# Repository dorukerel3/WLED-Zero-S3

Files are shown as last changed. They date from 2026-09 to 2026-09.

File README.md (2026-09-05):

# WLED-Zero-S3

A complete, self-contained hardware and firmware project for a custom addressable LED lighting system: a custom-designed **ESP32-S3 controller motherboard**, three **daisy-chainable WS2812B light stick PCBs**, and a tailored build of **[WLED](https://github.com/wled/WLED) v16.0.1** configured for the exact hardware. This repository contains everything needed to reproduce the system end to end — Gerber and drill files, pick-and-place data, bills of materials, 3D STEP models, the full patched firmware source tree, and a pre-built single-file flash image.

---

## Table of Contents

- [Project Overview](#project-overview)
- [Hardware Gallery](#hardware-gallery)
- [System Architecture](#system-architecture)
- [Key Features](#key-features)
- [Motherboard](#motherboard)
- [Light Sticks](#light-sticks)
- [Firmware Customizations](#firmware-customizations)
- [Repository Contents](#repository-contents)
- [Fabrication and Assembly Files](#fabrication-and-assembly-files)
- [Flashing the Pre-Built Release](#flashing-the-pre-built-release)
- [First Boot](#first-boot)
- [Building the Firmware from Source](#building-the-firmware-from-source)
- [Author and License](#author-and-license)

---

## Project Overview

The system consists of a controller motherboard and three purpose-built LED PCBs ("light sticks") of graduated lengths. The motherboard hosts a bare **ESP32-S3-WROOM-1-N16R8** module, USB-C power and programming, Li-ion battery charging, 3.3 V regulation, a 5 V logic-level shifter for the LED data line, and a MOSFET high-side power switch that lets the firmware cut power to the LED chain entirely.

The three light sticks carry **11**, **6**, and **4** WS2812B LEDs respectively — **21 in total**, which is exactly what the firmware is compiled for (`PIXEL_COUNTS=21`). The firmware is a minimal, targeted fork of WLED `v16.0.1`: one new build environment and a one-line source patch that makes the boot power state a compile-time default, so a freshly flashed unit ships with its LED power stage off and correct switch polarity, with zero post-flash configuration.

---

## Hardware Gallery

The physical production results of the custom-designed hardware, motherboard and light sticks:

### Motherboard
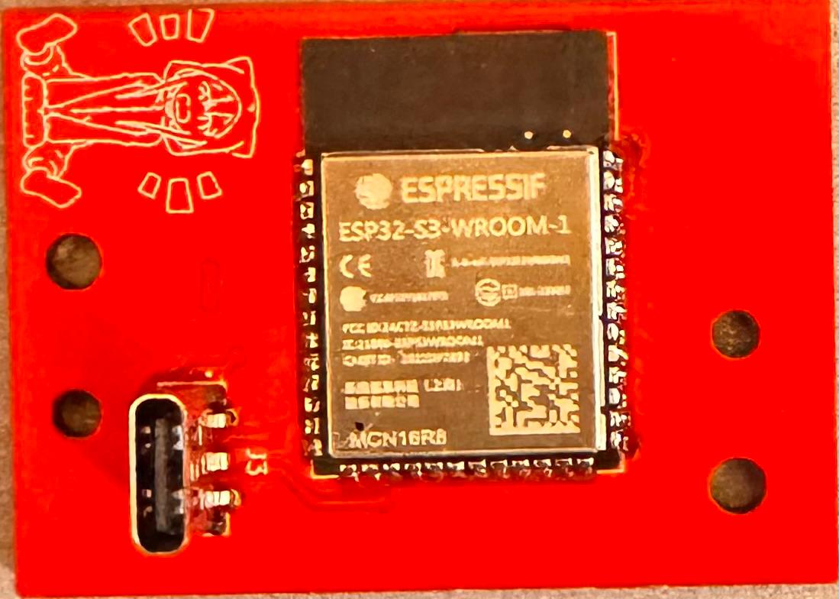
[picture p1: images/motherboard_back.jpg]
Motherboard Back
Motherboard Front 

### Longest Light Stick
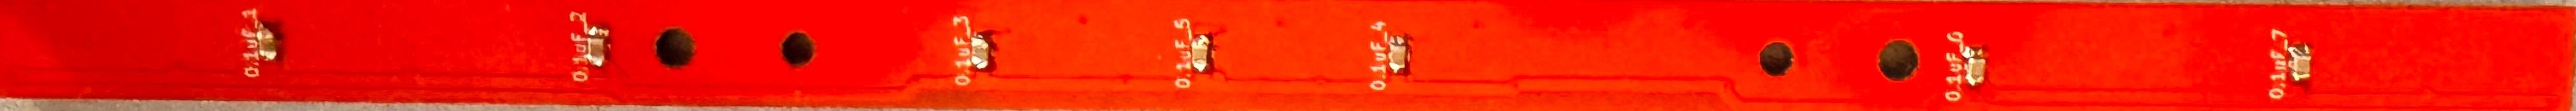
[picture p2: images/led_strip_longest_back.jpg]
Longest Light Stick Back
Longest Light Stick Front 

### Middle Light Stick
Middle Light Stick Front Middle Light Stick Back

### Shortest Light Stick
Shortest Light Stick Front Shortest Light Stick Back

---

## System Architecture

```text
 USB-C (GCT USB4220) ──► TP4057 Li-ion charger ──► Battery (B+/B− pads)
        │                                              │
        └────────────► AP2112K-3.3 LDOs ──► 3.3 V rail ──► ESP32-S3-WROOM-1-N16R8
                                                               │           │
                                            GPIO1 (LED data) ──┘           └── GPIO2 (power switch)
                                                   │                              │
                                       74AHCT1G125 level shifter        N-MOS + P-MOS high-side switch
                                                   │                              │
                                                   ▼                              ▼
                                     DIN ► Longest stick (11× WS2812B) ► Middle stick (6×) ► Shortest stick (4×)
                                                        21 LEDs total, switched 5 V rail
```

- **Data path:** the ESP32-S3 drives the WS2812B chain from `GPIO1` through a **74AHCT1G125** buffer, shifting the 3.3 V signal to clean 5 V logic for reliable data at full supply voltage.
- **Power path:** `GPIO2` controls an **N-channel + P-channel MOSFET high-side switch** (active-high) so the entire LED rail can be de-energized in software — true zero standby draw on the strip, not just black pixels.
- **Chaining:** each stick exposes `5V`, `GND`, `DIN`/`DOUT` pads, so the three boards cascade into a single 21-pixel logical strip.

---

## Key Features

- **Off-by-default boot state**, via a new `WLED_TURN_ON_AT_BOOT` compile-time flag patched into WLED's source (upstream hardcodes it to always-on).
- **Correct power-switch polarity out of the box** (`RLYPIN=2`, `RLYMDE=1`), matched to the board's active-high MOSFET high-side switch topology.
- **Single merged flashable image** — bootloader, partition table, and application combined into one `.bin` written at offset `0x0`. No multi-offset flashing.
- **16 MB flash / 8 MB octal PSRAM support**, targeting the ESP32-S3-WROOM-1-N16R8 module specifically.
- **Complete fabrication package** for all four PCBs: Gerbers, drill files, pick-and-place, BOM, and 3D STEP models.
- **Built on a stable upstream release** (`v16.0.1`), with the full source tree preserved in-repo for reproducible builds and future upstream syncs.

---

## Motherboard

| Component | Part | Package | Role |
|---|---|---|---|
| U2 | ESP32-S3-WROOM-1 (N16R8) | RF module | MCU — 16 MB flash, 8 MB octal-SPI PSRAM, WiFi/BLE |
| J3 | GCT USB4220-03-1040-C | USB-C receptacle | Power input and USB programming |
| TP4057 | TP4057 | TSOT-23-6 | Single-cell Li-ion charge management |
| AP2112_1, AP2112_2 | AP2112K-3.3 | SOT-23-5 | 3.3 V LDO regulation |
| U4 | 74AHCT1G125 | SOT-23-5 | 3.3 V → 5 V LED data level shifting |
| NMOSS1 | N-channel MOSFET | SOT-23 | Gate driver stage for the high-side switch |
| PMOSS1 | P-channel MOSFET | SOT-23 | High-side power switch for the LED rail |
| — | 8× resistors (2×1 kΩ, 2×5.1 kΩ, 3×10 kΩ, 1×330 Ω) | 0805 | Gate drive, CC1/CC2 termination, pull-ups, charge programming |
| — | 2× 1 µF capacitors | 0805 | LDO input/output decoupling |
| J2 | 1×4 pin header (DNP) | 2.54 mm | Auxiliary/debug header |
| — | 5× test points (`5V`, `B+`, `B−`, `DIN`, `GND`) | 3.0 mm pads | Bring-up and battery/strip wiring |

Full references, footprints, and datasheet links are in [`Motherboard_Files/Motherboard.csv`](Motherboard_Files/Motherboard.csv); exact placement coordinates in [`Motherboard_Files/Motherboard-all-pos.csv`](Motherboard_Files/Motherboard-all-pos.csv).

### Firmware pin map

| Signal | Pin | Configuration |
|---|-----|---|
| LED data out | GPIO1 | `DATA_PINS=1` |
| LED power switch | GPIO2 | `RLYPIN=2`, `RLYMDE=1` (active-high) |
| LED count | — | `PIXEL_COUNTS=21` |
| Flash | — | 16 MB, DIO, 40 MHz |

---

## Light Sticks

Three variants of the same design language — a 5 V WS2812B chain with per-LED 0.1 µF decoupling and pad-based chaining:

| Board | WS2812B count | Decoupling caps | Pads |
|---|---|---|---|
| Longest | 11 | 7× 0.1 µF | `5V`, `DIN`, `GND`, + |
| Middle | 6 | 3× 0.1 µF | `5V`, `DOUT`, `GND`, TP1–TP3 |
| Shortest | 4 | 2× 0.1 µF | `5V`, `DIN`, `DOUT`, `GND`, `VDD`, `VSS` |

**Total: 21 LEDs**, matching the firmware's compiled pixel count exactly. All LEDs use the `WS2812B PLCC4 5.0×5.0 mm` footprint on a 3.2 mm pitch.

---

## Firmware Customizations

Two changes on top of a clean `v16.0.1` checkout, both preserved in [`Motherboard_Files/firmware/`](Motherboard_Files/firmware/):

**[`platformio_override.ini`](Motherboard_Files/firmware/platformio_override.ini)** (new file) defines the `esp32s3` build environment:

```ini
[env:esp32s3]
extends = env:esp32s3dev_16MB_opi
build_flags = ${env:esp32s3dev_16MB_opi.build_flags}
  -D WLED_RELEASE_NAME=\"ESP32S3_Custom\"
  -D DATA_PINS=1
  -D PIXEL_COUNTS=21
  -D RLYPIN=2
  -D RLYMDE=1
  -D WLED_TURN_ON_AT_BOOT=false
```

**[`wled00/wled.h`](Motherboard_Files/firmware/wled00/wled.h)** carries a one-line patch exposing `turnOnAtBoot` as a build flag, since upstream WLED hardcodes it:

```diff
// LED CONFIG
-WLED_GLOBAL bool turnOnAtBoot _INIT(true);                 // turn on LEDs at power-up
+#ifndef WLED_TURN_ON_AT_BOOT
+  #define WLED_TURN_ON_AT_BOOT true
+#endif
+WLED_GLOBAL bool turnOnAtBoot _INIT(WLED_TURN_ON_AT_BOOT); // turn on LEDs at power-up
```

This build sets the flag to `false`, so the LED power stage never energizes without explicit user action.

---

## Repository Contents

```text
.
├── Motherboard_Files/
│   ├── firmware/                                        Full WLED v16.0.1 source tree (patched: wled00/wled.h,
│   │                                                    new: platformio_override.ini)
│   ├── WLED_16.0.1_ESP32-S3_16MB_opi_MERGED_dio40m_v2.bin   Pre-built merged flash image (write at 0x0)
│   ├── Motherboard_Gerber&Drill.zip                     Fabrication files (Cu, mask, paste, silkscreen, edge cuts, PTH/NPTH drill)
│   ├── Motherboard.csv                                  Bill of materials
│   ├── Motherboard-all-pos.csv                          Pick-and-place component positions
│   └── Motherboard_Design.step                          3D model
├── Longest_Light_Stick_Files/                           11× WS2812B — pads: 5V, DIN, GND
│   ├── Longest_light_stick_Gerber&Drill.zip             Fabrication files (Cu, mask, paste, silkscreen, edge cuts, PTH/NPTH drill)
│   ├── Longest_light_stick.csv                          Bill of materials (11× WS2812B, 7× 0.1 µF 0805)
│   ├── Longest_light_stick-all-pos.csv                  Pick-and-place component positions
│   └── Longest_Light_Stick_Design.step                  3D model
├── Middle_Light_Stick_Files/                            6× WS2812B — pads: 5V, DOUT, GND, TP1–TP3
│   ├── Middle_light_stick_Gerber&Drill.zip              Fabrication files (Cu, mask, paste, silkscreen, edge cuts, PTH/NPTH drill)
│   ├── Middle_light_stick.csv                           Bill of materials (6× WS2812B, 3× 0.1 µF 0805)
│   ├── Middle_light_stick-all-pos.csv                   Pick-and-place component positions
│   └── Middle_Light_Stick_Design.STEP                   3D model
├── Shortest_Light_Stick_Files/                          4× WS2812B — pads: 5V, DIN, DOUT, GND, VDD, VSS
│   ├── Shortest_light_stick_Gerber&Drill.zip            Fabrication files (Cu, mask, paste, silkscreen, edge cuts, PTH/NPTH drill)
│   ├── Shortest_light_stick.csv                         Bill of materials (4× WS2812B, 2× 0.1 µF 0805)
│   ├── Shortest_light_stick-all-pos.csv                 Pick-and-place component positions
│   └── Shortest_Light_Stick_Design.STEP                 3D model
├── images/                                              README gallery assets
│   ├── motherboard_front.jpg                            Assembled motherboard, component side
│   ├── motherboard_back.jpg                             Assembled motherboard, reverse side
│   ├── led_strip_longest_front.jpg                      Longest light stick, LED side
│   ├── led_strip_longest_back.jpg                       Longest light stick, reverse side
│   ├── led_strip_middle_front.jpg                       Middle light stick, LED side
│   ├── led_strip_middle_back.jpg                        Middle light stick, reverse side
│   ├── led_strip_shortest_front.jpg                     Shortest light stick, LED side
│   └── led_strip_shortest_back.jpg                      Shortest light stick, reverse side
├── LICENSE                                              MIT license
└── README.md                                            This document
```

---

## Fabrication and Assembly Files

Each of the four PCB folders is a complete manufacturing package:

- **`*_Gerber&Drill.zip`** — full Gerber set (front/back copper, solder mask, paste, silkscreen, board outline) plus PTH and NPTH Excellon drill files, ready to upload to any fab (JLCPCB, PCBWay, etc.).
- **`*.csv`** — the bill of materials with references, quantities, footprints, and datasheet links.
- **`*-all-pos.csv`** — pick-and-place position files (X/Y, rotation, side) for assembly services.
- **`*.step`** — 3D STEP models for enclosure design and mechanical verification.

---

## Flashing the Pre-Built Release

1. Download [`Motherboard_Files/WLED_16.0.1_ESP32-S3_16MB_opi_MERGED_dio40m_v2.bin`](Motherboard_Files/WLED_16.0.1_ESP32-S3_16MB_opi_MERGED_dio40m_v2.bin).
2. Install [esptool](https://github.com/espressif/esptool):
   ```bash
   python -m pip install esptool
   ```
3. Put the board into download mode if it doesn't reset into it automatically: hold **BOOT**, tap **RESET**, release **BOOT**.
4. Erase and flash (replace `COMx` with the board's serial port):
   ```bash
   python -m esptool --chip esp32s3 --port COMx erase_flash
   python -m esptool --chip esp32s3 --port COMx --baud 921600 write_flash 0x0 WLED_16.0.1_ESP32-S3_16MB_opi_MERGED_dio40m_v2.bin
   ```
   The image is a single merge of bootloader, partition table, and application, so it is written at offset `0x0` with no further offsets needed.

---

## First Boot

1. The board opens a WiFi access point named `WLED-AP`, password `wled1234`.
2. Connect to it and browse to `4.3.2.1` to enter your home WiFi credentials.
3. Once joined, reach the UI at `http://wled-XXXXXX.local` (`XXXXXX` is the last 6 hex digits of the board's MAC address — visible in the esptool output during flashing, or via your router's DHCP client list if `.local` doesn't resolve).
4. LEDs and the power switch stay off on every boot by default — no configuration required. Turn them on from the UI when ready.

---

<p align="center">
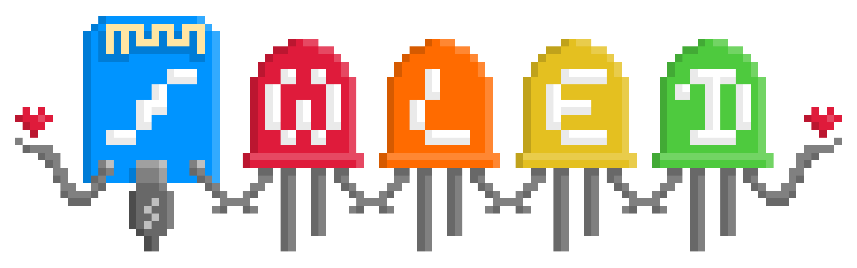
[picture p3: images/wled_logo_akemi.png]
WLED Akemi logo
  
</p>

## Building the Firmware from Source

```bash
git clone https://github.com/dorukerel3/WLED-Zero-S3.git
cd WLED-Zero-S3/Motherboard_Files/firmware
python -m pip install platformio
python -m platformio run -e esp32s3
```

This produces `.pio/build/esp32s3/firmware.bin` (application only). To reproduce the merged single-file release image:

```bash
python -m esptool --chip esp32s3 merge_bin \
  -o WLED_16.0.1_ESP32-S3_16MB_opi_MERGED_dio40m_v2.bin \
  --flash_mode dio --flash_freq 40m --flash_size 16MB \
  0x0     .pio/build/esp32s3/bootloader.bin \
  0x8000  .pio/build/esp32s3/partitions.bin \
  0x10000 .pio/build/esp32s3/firmware.bin
```

---

## Author and License

Designed and developed by **Doruk Erel** — [dorukerel.com](https://dorukerel.com).

Firmware based on [WLED](https://github.com/wled/WLED). Released under the **MIT License**. See the [`LICENSE`](LICENSE) file for the full text.

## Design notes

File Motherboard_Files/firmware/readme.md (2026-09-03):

# Custom WLED Board (ESP32-S3)

A custom firmware build of [WLED](https://github.com/wled/WLED) v16.0.1, targeting a bare **ESP32-S3-WROOM-1-N16R8** module driving an addressable LED strip through a GPIO-switched MOSFET power stage. Developed as the firmware layer for a custom-designed LED controller board, the build is configured so that a freshly flashed unit ships with LEDs off and correct power-switch polarity by default, with no post-flash configuration required. PCB fabrication and assembly (motherboard and light stick designs) are documented separately via their own Gerber deliverables and are outside the scope of this repository.

---

## Table of Contents

- [Project Overview](#project-overview)
- [Hardware Gallery](#hardware-gallery)
- [Key Features](#key-features)
- [Hardware Specifications](#hardware-specifications)
- [Firmware Customizations](#firmware-customizations)
- [Repository Contents](#repository-contents)
- [Flashing a Pre-Built Release](#flashing-a-pre-built-release)
- [First Boot](#first-boot)
- [Building from Source](#building-from-source)
- [Author and License](#author-and-license)

---

## Project Overview

This repository is a `v16.0.1` fork of WLED with a minimal, targeted set of changes on top: a PlatformIO build environment for the ESP32-S3-WROOM-1-N16R8 module, and a one-line source patch that makes the "turn on at boot" behavior a compile-time default instead of a runtime setting a user has to configure. Everything else is unmodified upstream WLED, retained via full git history so the fork can track future upstream releases.

The goal is an appliance-grade default: a unit flashed straight from a release binary boots with its LED power stage off and correctly oriented for the board's MOSFET switching circuit, without requiring anyone to open the web UI and change settings first.

---

## Hardware Gallery

The physical production results of the custom-designed hardware, motherboard and light sticks:

### Motherboard
Motherboard Front Motherboard Back

### Longest Light Stick
Longest Light Stick Front Longest Light Stick Back

### Middle Light Stick
Middle Light Stick Front Middle Light Stick Back

### Shortest Light Stick
Shortest Light Stick Front Shortest Light Stick Back

---

## Key Features

- **Off-by-default boot state**, via a new `WLED_TURN_ON_AT_BOOT` compile-time flag patched into WLED's source (upstream hardcodes this to always-on).
- **Correct power-switch polarity out of the box**, matching the board's N-channel + P-channel MOSFET high-side switch topology.
- **Single merged flashable image**, combining bootloader, partition table, and application into one `.bin` written at offset `0x0` — no multi-offset flashing required.
- **16MB flash / 8MB octal PSRAM support**, targeting the ESP32-S3-WROOM-1-N16R8 module specifically.
- **Built on a stable upstream release** (`v16.0.1`), with the fork's full commit history preserved for future upstream syncs.

---

## Hardware Specifications

| Component | Specification |
|---|---|
| Microcontroller | `ESP32-S3-WROOM-1-N16R8` — 16 MB flash, 8 MB octal-SPI PSRAM |
| LED data pin | GPIO1 |
| LED count | 21 |
| Power switch pin | GPIO2, active-low, driving an N-channel + P-channel MOSFET high-side switch |
| Flash configuration | 16 MB, DIO mode, 40 MHz |

---

## Firmware Customizations

Two changes on top of a clean `v16.0.1` checkout, both committed in this repository's history:

**`platformio_override.ini`** (new file) defines the `esp32s3` build environment — pin assignments, LED count, relay/MOSFET pin and polarity, and release naming.

**`wled00/wled.h`** carries a one-line patch exposing `turnOnAtBoot` as a build flag, since upstream WLED hardcodes it:

```diff
// LED CONFIG
-WLED_GLOBAL bool turnOnAtBoot _INIT(true);                // turn on LEDs at power-up
+#ifndef WLED_TURN_ON_AT_BOOT
+  #define WLED_TURN_ON_AT_BOOT true
+#endif
+WLED_GLOBAL bool turnOnAtBoot _INIT(WLED_TURN_ON_AT_BOOT); // turn on LEDs at power-up
```

This build sets the flag to `false`, so the power stage never energizes without explicit user action.

---

## Repository Contents

```text
.
├── wled00/                 WLED firmware source (patched: wled.h)
├── boards/                 Board pin-mapping definitions
├── lib/                    Bundled third-party libraries
├── tools/                  Build tooling and custom partition tables
├── platformio.ini          Upstream WLED build environments
├── platformio_override.ini Custom esp32s3 build environment (this fork's config)
├── LICENSE                 Upstream MIT license
└── readme.md
```

The repository is otherwise a standard WLED checkout — see the [upstream project](https://github.com/wled/WLED) for full documentation on the underlying firmware.

---

## Flashing a Pre-Built Release

1. Download the latest merged `.bin` from the [Releases](../../releases) page.
2. Install [esptool](https://github.com/espressif/esptool):
   ```bash
   python -m pip install esptool
   ```
3. Put the board into download mode if it doesn't reset into it automatically: hold **BOOT**, tap **RESET**, release **BOOT**.
4. Erase and flash (replace `COMx` with the board's serial port):
   ```bash
   python -m esptool --chip esp32s3 --port COMx erase_flash
   python -m esptool --chip esp32s3 --port COMx --baud 921600 write_flash 0x0 WLED_ESP32-S3_16MB_opi_MERGED.bin
   ```
   The image is a single merge of bootloader, partition table, and application, so it's written at offset `0x0` with no further offsets needed.

---

## First Boot

1. The board opens a WiFi access point named `WLED-AP`, password `wled1234`.
2. Connect to it and browse to `4.3.2.1` to enter your home WiFi credentials.
3. Once joined, reach the UI at `http://wled-XXXXXX.local` (`XXXXXX` is the last 6 hex digits of the board's MAC address — visible in the esptool output during flashing, or via your router's DHCP client list if `.local` doesn't resolve).
4. LEDs and the power switch stay off on every boot by default — no configuration required. Turn them on from the UI when ready.

---

## Building from Source

```bash
git clone <this-repo-url>
cd <this-repo>
python -m pip install platformio
python -m platformio run -e esp32s3
```

This produces `.pio/build/esp32s3/firmware.bin` (application only). To reproduce the merged, single-file release image:

```bash
python -m esptool --chip esp32s3 merge_bin \
  -o WLED_ESP32-S3_16MB_opi_MERGED.bin \
  --flash_mode dio --flash_freq 40m --flash_size 16MB \
  0x0     .pio/build/esp32s3/bootloader.bin \
  0x8000  .pio/build/esp32s3/partitions.bin \
  0x10000 .pio/build/esp32s3/firmware.bin
```

---

## Author and License

Developed by **Doruk Erel**.

Based on [WLED](https://github.com/wled/WLED). Released under the **MIT License**. See the `LICENSE` file for the full text.

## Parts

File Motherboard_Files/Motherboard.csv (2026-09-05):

Id | Designator | Footprint | Quantity | Designation | Supplier and ref
1 | 1KOHM_1, 1KOHM_2, 5.1kohm_1, 5.1kohm_2, 10Kohm_1, 10Kohm_2, 10Kohm_3, 330ohm_1 | R_0805_2012Metric_Pad1.20x1.40mm_HandSolder | 8 | R
2 | 1uF_1, 1uF_2 | C_0805_2012Metric_Pad1.18x1.45mm_HandSolder | 2 | C
3 | 5V1, B+1, B-1, DIN1, GND1 | TestPoint_Pad_3.0x3.0mm | 5 | TestPoint_Square
4 | 74AHCT1G125 | SOT-23-5_HandSoldering | 1 | 74AHCT1G125
5 | AP2112_1, AP2112_2 | SOT-23-5 | 2 | AP2112K-3.3
6 | D_Schottky_1, D_Schottky_2 | D_SMA_Handsoldering | 2 | D_Schottky
7 | J3 | GCT_USB4220-03-1040-C_REVA | 1 | USB4220-03-1040-C_REVA
8 | NMOSS1 | SOT-23 | 1 | Q_NMOS_GSD
9 | PMOSS1 | SOT-23 | 1 | Q_PMOS_GSD
10 | TP4057 | TSOT-23-6 | 1 | TP4057
11 | U2 | ESP32-S3-WROOM-1 | 1 | ESP32-S3-WROOM-1

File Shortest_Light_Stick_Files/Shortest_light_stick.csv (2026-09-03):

Id | Designator | Footprint | Quantity | Designation | Supplier and ref
1 | 0.1uF_1, 0.1uF_2 | C_0805_2012Metric_Pad1.18x1.45mm_HandSolder | 2 | C
2 | 5V, DIN, DOUT, GND, VDD, VSS | TestPoint_Pad_3.0x3.0mm | 6 | TestPoint_Square
3 | D1, D2, D3, D4 | LED_WS2812B_PLCC4_5.0x5.0mm_P3.2mm | 4 | WS2812B

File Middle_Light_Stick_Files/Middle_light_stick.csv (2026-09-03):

Id | Designator | Footprint | Quantity | Designation | Supplier and ref
1 | 0.1uF_1, 0.1uF_2, 0.1uF_3 | C_0805_2012Metric_Pad1.18x1.45mm_HandSolder | 3 | C
2 | 5V, DOUT, GND, TP1, TP2, TP3 | TestPoint_Pad_3.0x3.0mm | 6 | TestPoint_Square
3 | D1, D2, D3, D4, D5, D6 | LED_WS2812B_PLCC4_5.0x5.0mm_P3.2mm | 6 | WS2812B

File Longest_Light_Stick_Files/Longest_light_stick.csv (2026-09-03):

Id | Designator | Footprint | Quantity | Designation | Supplier and ref
1 | 0.1uF_1, 0.1uF_2, 0.1uF_3, 0.1uF_4, 0.1uF_5, 0.1uF_6, 0.1uF_7 | C_0805_2012Metric_Pad1.18x1.45mm_HandSolder | 7 | C
2 | 5V | TestPoint_Pad_3.0x3.0mm | 1 | 5V
3 | D1, D2, D3, D4, D5, D6, D10, D11, D12, D13, D14 | LED_WS2812B_PLCC4_5.0x5.0mm_P3.2mm | 11 | WS2812B
4 | DIN | TestPoint_Pad_3.0x3.0mm | 1 | DIN
5 | DOUT | TestPoint_Pad_3.0x3.0mm | 1 | DOUT
6 | GND | TestPoint_Pad_3.0x3.0mm | 1 | GND
7 | VDD | TestPoint_Pad_3.0x3.0mm | 1 | VDD
8 | VSS | TestPoint_Pad_3.0x3.0mm | 1 | VSS

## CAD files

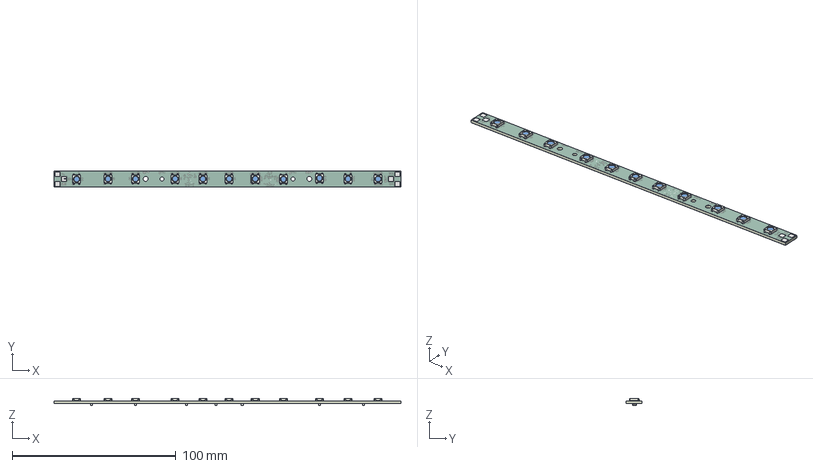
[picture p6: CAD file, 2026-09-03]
Longest_Light_Stick_Files/Longest_Light_Stick_Design.step
212.0 x 10.0 x 4.53 mm
LED_WS2812B_PLCC4_5.0x5.0mm_P3.2mm x 11
C_0805_2012Metric x 7
Longest_light_stick_copper
Longest_light_stick_pad
Longest_light_stick_via
Longest_light_stick_silkscreen x 2
Longest_light_stick_soldermask x 2
Longest_light_stick_PCB

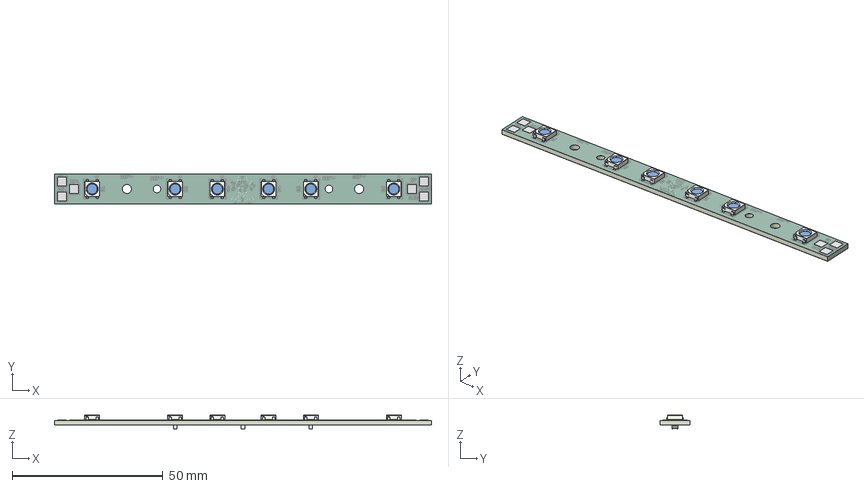
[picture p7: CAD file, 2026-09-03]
Middle_Light_Stick_Files/Middle_Light_Stick_Design.STEP
125.0 x 10.0 x 4.53 mm
LED_WS2812B_PLCC4_5.0x5.0mm_P3.2mm x 6
C_0805_2012Metric x 3
Middle_light_stick_copper
Middle_light_stick_pad
Middle_light_stick_via
Middle_light_stick_silkscreen x 2
Middle_light_stick_soldermask x 2
Middle_light_stick_PCB

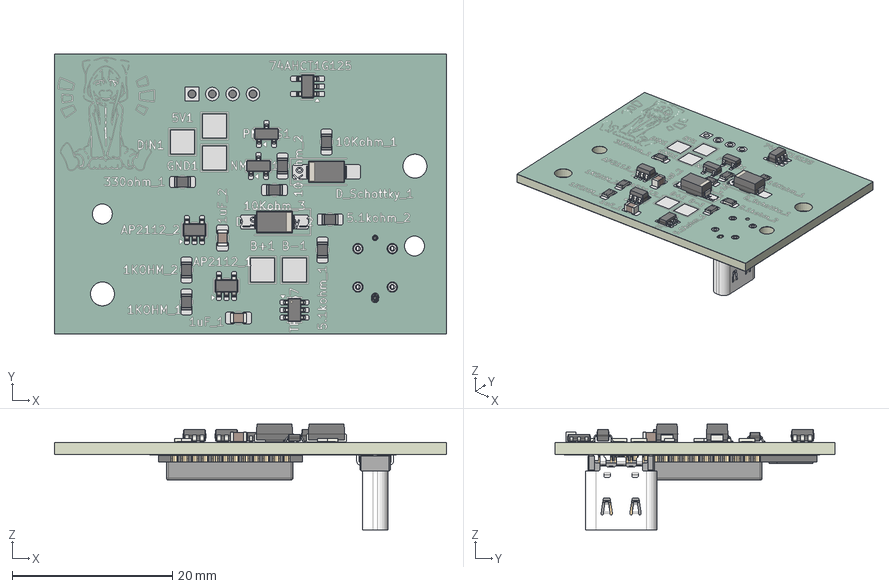
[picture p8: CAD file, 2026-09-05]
Motherboard_Files/Motherboard_Design.STEP
49.0 x 35.0 x 13.2 mm
D_SMA x 2
R_0805_2012Metric x 8
SOT-23-5 x 3
SOT-23 x 2
C_0805_2012Metric x 2
TSOT-23-6
USB4220-03-0930-C_PART1
USB4220-03-0930-C_PART2
ESP32-S3-WROOM-1
Motherboard_copper
Motherboard_pad
Motherboard_via
Motherboard_silkscreen x 2
Motherboard_soldermask x 2
Motherboard_PCB

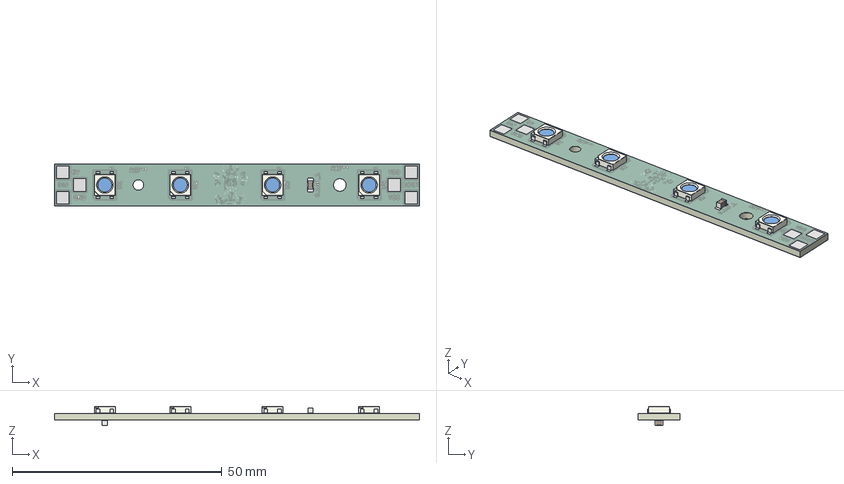
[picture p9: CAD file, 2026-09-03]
Shortest_Light_Stick_Files/Shortest_Light_Stick_Design.STEP
87.0 x 10.0 x 4.53 mm
LED_WS2812B_PLCC4_5.0x5.0mm_P3.2mm x 4
C_0805_2012Metric x 2
Shortest_light_stick_copper
Shortest_light_stick_pad
Shortest_light_stick_via
Shortest_light_stick_silkscreen x 2
Shortest_light_stick_soldermask x 2
Shortest_light_stick_PCB

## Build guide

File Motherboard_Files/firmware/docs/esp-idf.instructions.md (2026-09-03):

---
applyTo: "**/*.cpp,**/*.h,**/*.hpp,**/*.ino"
---
# ESP-IDF Coding Guide (within arduino-esp32)

WLED runs on the Arduino-ESP32 framework, which wraps ESP-IDF. Understanding the ESP-IDF layer is essential when writing chip-specific code, managing peripherals, or preparing for the IDF v5.x migration. This guide documents patterns already used in the codebase and best practices derived from Espressif's official examples.

> **Scope**: This file is an optional review guideline. It applies when touching chip-specific code, peripheral drivers, memory allocation, or platform conditionals.

> **Note for AI review tools**: sections enclosed in
> `<!-- HUMAN_ONLY_START -->` / `<!-- HUMAN_ONLY_END -->` HTML comments contain
> contributor reference material. Do **not** use that content as actionable review
> criteria — treat it as background context only.

---

<!-- HUMAN_ONLY_START -->
## Identifying the Build Target: `CONFIG_IDF_TARGET_*`

Use `CONFIG_IDF_TARGET_*` macros to gate chip-specific code at compile time. These are set by the build system and are mutually exclusive — exactly one is defined per build.

| Macro | Chip | Architecture | Notes |
|---|---|---|---|
| `CONFIG_IDF_TARGET_ESP32` | ESP32 (classic) | Xtensa dual-core | Primary target. Has DAC, APLL, I2S ADC mode |
| `CONFIG_IDF_TARGET_ESP32S2` | ESP32-S2 | Xtensa single-core | Limited peripherals. 13-bit ADC |
| `CONFIG_IDF_TARGET_ESP32S3` | ESP32-S3 | Xtensa dual-core | Preferred for large installs. Octal PSRAM, USB-OTG |
| `CONFIG_IDF_TARGET_ESP32C3` | ESP32-C3 | RISC-V single-core | Minimal peripherals. RISC-V clamps out-of-range float→unsigned casts |
| `CONFIG_IDF_TARGET_ESP32C5` | ESP32-C5 | RISC-V single-core | Wi-Fi 2.4Ghz + 5Ghz, Thread/Zigbee. Future target |
| `CONFIG_IDF_TARGET_ESP32C6` | ESP32-C6 | RISC-V single-core | Wi-Fi 6, Thread/Zigbee. Future target |
| `CONFIG_IDF_TARGET_ESP32P4` | ESP32-P4 | RISC-V dual-core | High performance. Future target |

<!-- HUMAN_ONLY_END -->
### Build-time validation
WLED validates at compile time that exactly one target is defined and that it is a supported chip (`wled.cpp` lines 39–61). Follow this pattern when adding new chip-specific branches:

<!-- HUMAN_ONLY_START -->
```cpp
#if defined(CONFIG_IDF_TARGET_ESP32)
  // classic ESP32 path
#elif defined(CONFIG_IDF_TARGET_ESP32S3)
  // S3-specific path
#elif defined(CONFIG_IDF_TARGET_ESP32C3) || defined(CONFIG_IDF_TARGET_ESP32C5) || defined(CONFIG_IDF_TARGET_ESP32C6) || defined(CONFIG_IDF_TARGET_ESP32P4)
  // RISC-V common path
#else
  #warning "Untested chip — review peripheral availability"
#endif
```

<!-- HUMAN_ONLY_END -->
### Guidelines

- **Always test on the actual chip** before claiming support. Simulators and cross-compilation can hide peripheral differences.
- **Prefer `#elif` chains** over nested `#ifdef` for readability.
- **Do not use `CONFIG_IDF_TARGET_*` for feature detection.** Use `SOC_*` capability macros instead (see next section). For example, use `SOC_I2S_SUPPORTS_ADC` instead of `CONFIG_IDF_TARGET_ESP32` to check for I2S ADC support.
- When a feature must be disabled on certain chips, use explicit `static_assert()` or `#warning` directives so the build clearly reports what is missing.

---

## Hardware Capability Detection: `SOC_*` Macros

`SOC_*` macros (from `soc/soc_caps.h`) describe what the current chip supports. They are the correct way to check for peripheral features — they stay accurate when new chips are added, unlike `CONFIG_IDF_TARGET_*` checks.

<!-- HUMAN_ONLY_START -->
### Important `SOC_*` macros used in WLED

| Macro | Type | Used in | Purpose |
|---|---|---|---|
| `SOC_I2S_NUM` | `int` | `audio_source.h` | Number of I2S peripherals (1 or 2) |
| `SOC_I2S_SUPPORTS_ADC` | `bool` | `usermods/audioreactive/audio_source.h` | I2S ADC sampling mode (ESP32 only) |
| `SOC_I2S_SUPPORTS_APLL` | `bool` | `usermods/audioreactive/audio_source.h` | Audio PLL for precise sample rates |
| `SOC_I2S_SUPPORTS_PDM_RX` | `bool` | `usermods/audioreactive/audio_source.h` | PDM microphone input |
| `SOC_ADC_MAX_BITWIDTH` | `int` | `util.cpp` | ADC resolution (12 or 13 bits). Renamed to `CONFIG_SOC_ADC_RTC_MAX_BITWIDTH` in IDF v5 |
| `SOC_ADC_CHANNEL_NUM(unit)` | `int` | `pin_manager.cpp` | ADC channels per unit |
| `SOC_UART_NUM` | `int` | `dmx_input.cpp` | Number of UART peripherals |
| `SOC_DRAM_LOW` / `SOC_DRAM_HIGH` | `addr` | `util.cpp` | DRAM address boundaries for validation |

<!-- HUMAN_ONLY_END -->
### Key pitfall
`SOC_ADC_MAX_BITWIDTH` (ADC resolution 12 or 13 bits) was renamed to `CONFIG_SOC_ADC_RTC_MAX_BITWIDTH` in IDF v5.

<!-- HUMAN_ONLY_START -->
### Less commonly used but valuable

| Macro | Purpose |
|---|---|
| `SOC_RMT_TX_CANDIDATES_PER_GROUP` | Number of RMT TX channels (varies 2–8 by chip) |
| `SOC_LEDC_CHANNEL_NUM` | Number of LEDC (PWM) channels |
| `SOC_GPIO_PIN_COUNT` | Total GPIO pin count |
| `SOC_DAC_SUPPORTED` | Whether the chip has a DAC (ESP32/S2 only) |
| `SOC_SPIRAM_SUPPORTED` | Whether PSRAM interface exists |
| `SOC_CPU_CORES_NUM` | Core count (1 or 2) — useful for task pinning decisions |

<!-- HUMAN_ONLY_END -->

### Best practices

```cpp
// Good: feature-based detection
#if SOC_I2S_SUPPORTS_PDM_RX
  _config.mode = i2s_mode_t(I2S_MODE_MASTER | I2S_MODE_RX | I2S_MODE_PDM);
#else
  #warning "PDM microphones not supported on this chip"
#endif

// Avoid: chip-name-based detection
#if defined(CONFIG_IDF_TARGET_ESP32) || defined(CONFIG_IDF_TARGET_ESP32S3)
  // happens to be correct today, but breaks when a new chip adds PDM support
#endif
```

<!-- HUMAN_ONLY_START -->
### PSRAM capability macros

For PSRAM presence, mode, and DMA access patterns:

| Macro | Meaning |
|---|---|
| `CONFIG_SPIRAM` / `BOARD_HAS_PSRAM` | PSRAM is present in the build configuration |
| `CONFIG_SPIRAM_MODE_QUAD` | Quad-SPI PSRAM (standard, used on ESP32 classic and some S2/S3 boards) |
| `CONFIG_SPIRAM_MODE_OCT` | Octal-SPI PSRAM — 8 data lines, DTR mode. Used on ESP32-S3 with octal PSRAM (e.g. N8R8 / N16R8 modules). Reserves GPIO 33–37 for the PSRAM bus — **do not allocate these pins** when this macro is defined. `wled.cpp` uses this to gate GPIO reservation. |
| `CONFIG_SPIRAM_MODE_HEX` | Hex-SPI (16-line) PSRAM — future interface on ESP32-P4 running at up to 200 MHz. Used in `json.cpp` to report the PSRAM mode. |
| `CONFIG_SOC_PSRAM_DMA_CAPABLE` | PSRAM buffers can be used with DMA (ESP32-S3 with octal PSRAM) |
| `CONFIG_SOC_MEMSPI_FLASH_PSRAM_INDEPENDENT` | SPI flash and PSRAM on separate buses (no speed contention) |

<!-- HUMAN_ONLY_END -->

#### Detecting octal/hex flash

On ESP32-S3 modules with OPI flash (e.g. N8R8 modules where the SPI flash itself runs in Octal-PI mode), the build system sets:

| Macro | Meaning |
|---|---|
| `CONFIG_ESPTOOLPY_FLASHMODE_OPI` | Octal-PI flash mode. On S3, implies GPIO 33–37 are used by the flash/PSRAM interface — the same GPIO block as octal PSRAM. `wled.cpp` uses `CONFIG_ESPTOOLPY_FLASHMODE_OPI \|\| (CONFIG_SPIRAM_MODE_OCT && BOARD_HAS_PSRAM)` to decide whether to reserve these GPIOs. `json.cpp` uses this to report the flash mode string as `"🚀OPI"`. |
| `CONFIG_ESPTOOLPY_FLASHMODE_HEX` | Hex flash mode (ESP32-P4). Reported as `"🚀🚀HEX"` in `json.cpp`. |

**Pattern used in WLED** (from `wled.cpp`) to reserve the octal-bus GPIOs on S3:
```cpp
#if defined(CONFIG_IDF_TARGET_ESP32S3)
  #if CONFIG_ESPTOOLPY_FLASHMODE_OPI || (CONFIG_SPIRAM_MODE_OCT && defined(BOARD_HAS_PSRAM))
    // S3: GPIO 33-37 are used by the octal PSRAM/flash bus
    managed_pin_type pins[] = { {33, true}, {34, true}, {35, true}, {36, true}, {37, true} };
    pinManager.allocateMultiplePins(pins, sizeof(pins)/sizeof(managed_pin_type), PinOwner::SPI_RAM);
  #endif
#endif
```

---

## ESP-IDF Version Conditionals

<!-- HUMAN_ONLY_START -->
### Checking the IDF version

```cpp
#include <esp_idf_version.h>

#if ESP_IDF_VERSION >= ESP_IDF_VERSION_VAL(5, 0, 0)
  // IDF v5+ code path
#elif ESP_IDF_VERSION >= ESP_IDF_VERSION_VAL(4, 4, 0)
  // IDF v4.4+ code path
#else
  // Legacy IDF v3/v4.x path
#endif
```

### Key ESP-IDF version thresholds for WLED

| Version | What changed |
|---|---|
| **4.0.0** | Filesystem API (`SPIFFS`/`LittleFS`), GPIO driver overhaul |
| **4.2.0** | ADC/GPIO API updates; `esp_adc_cal` introduced |
| **4.4.0** | I2S driver refactored (legacy API remains); `adc_deprecated.h` headers appear for newer targets |
| **4.4.4–4.4.8** | Known I2S channel-swap regression on ESP32 (workaround in `audio_source.h`) |
| **5.0.0** | **Major breaking changes** — RMT, I2S, ADC, SPI flash APIs replaced (see migration section) |
| **5.1.0** | Matter protocol support; new `esp_flash` API stable |
| **5.3+** | arduino-esp32 v3.x compatibility; C6/P4 support |

<!-- HUMAN_ONLY_END -->
### Guidelines

- When adding a version guard, **always include a comment** explaining *what* changed and *why* the guard is needed.
- Avoid version ranges that silently break — prefer `>=` over exact version matches.
- Known regressions should use explicit range guards:
  ```cpp
  // IDF 4.4.4–4.4.8 swapped I2S left/right channels (fixed in 4.4.9)
  #if (ESP_IDF_VERSION >= ESP_IDF_VERSION_VAL(4, 4, 4)) && \
      (ESP_IDF_VERSION <= ESP_IDF_VERSION_VAL(4, 4, 8))
    #define I2S_CHANNELS_SWAPPED
  #endif
  ```

---

## Migrating from ESP-IDF v4.4.x to v5.x

The jump from IDF v4.4 (arduino-esp32 v2.x) to IDF v5.x (arduino-esp32 v3.x) is the largest API break in ESP-IDF history. This section documents the critical changes and recommended migration patterns based on the upstream WLED `V5` branch (`https://github.com/wled/WLED/tree/V5`). Note: WLED has not yet migrated to IDF v5 — these patterns prepare for the future migration.

<!-- HUMAN_ONLY_START -->
### Compiler changes

IDF v5.x ships a much newer GCC toolchain. Key versions:

| ESP-IDF | GCC | C++ default | Notes |
|---|---|---|---|
| 4.4.x (current) | **8.4.0** | C++17 (gnu++17) | Xtensa + RISC-V |
| 5.1–5.3 | **13.2** | C++20 (gnu++2b) | Significant warning changes |
| 5.4–5.5 | **14.2** | C++23 (gnu++2b) | Latest; stricter diagnostics |

Notable behavioral differences:

| Change | Impact | Action |
|---|---|---|
| Stricter `-Werror=enum-conversion` | Implicit int-to-enum casts now error | Use explicit `static_cast<>` or typed enums |
| C++20/23 features available | `consteval`, `concepts`, `std::span`, `std::expected` | Use judiciously — ESP8266 builds still require GCC 10.x with C++17 |
| `-Wdeprecated-declarations` enforced | Deprecated API calls become warnings/errors | Migrate to new APIs (see below) |
| `-Wdangling-reference` (GCC 13+) | Warns when a reference binds to a temporary that will be destroyed | Fix the lifetime issue; do not suppress the warning |
| `-fno-common` default (GCC 12+) | Duplicate tentative definitions across translation units cause linker errors | Use `extern` declarations in headers, define in exactly one `.cpp` |
| RISC-V codegen improvements | C3/C6/P4 benefit from better register allocation | No action needed — automatic |

### C++ language features: GCC 8 → GCC 14

The jump from GCC 8.4 to GCC 14.2 spans six major compiler releases. This section lists features that become available and patterns that need updating.

#### Features safe to use after migration

These work in GCC 13+/14+ but **not** in GCC 8.4. Guard with `#if ESP_IDF_VERSION >= ESP_IDF_VERSION_VAL(5, 0, 0)` if the code must compile on both IDF v4 and v5.

| Feature | Standard | Example | Benefit |
|---|---|---|---|
| Designated initializers (C++20) | C++20 | `gpio_config_t cfg = { .mode = GPIO_MODE_OUTPUT };` | Already used as a GNU extension in GCC 8; becomes standard and portable in C++20 |
| `[[likely]]` / `[[unlikely]]` | C++20 | `if (err != ESP_OK) [[unlikely]] { ... }` | Hints for branch prediction; useful in hot paths |
| `[[nodiscard("reason")]]` | C++20 | `[[nodiscard("leak if ignored")]] void* allocBuffer();` | Enforces checking return values — helpful for `esp_err_t` wrappers |
| `std::span<T>` | C++20 | `void process(std::span<uint8_t> buf)` | Safe, non-owning view of contiguous memory — replaces raw pointer + length pairs |
| `consteval` | C++20 | `consteval uint32_t packColor(...)` | Guarantees compile-time evaluation; useful for color constants |
| `constinit` | C++20 | `constinit static int counter = 0;` | Prevents static initialization order fiasco |
| Concepts / `requires` | C++20 | `template<typename T> requires std::integral<T>` | Clearer constraints than SFINAE; improves error messages |
| Three-way comparison (`<=>`) | C++20 | `auto operator<=>(const Version&) const = default;` | Less boilerplate for comparable types |
| `std::bit_cast` | C++20 | `float f = std::bit_cast<float>(uint32_val);` | Type-safe reinterpretation — replaces `memcpy` or `union` tricks |
| `if consteval` | C++23 | `if consteval { /* compile-time */ } else { /* runtime */ }` | Cleaner than `std::is_constant_evaluated()` |
| `std::expected<T, E>` | C++23 | `std::expected<int, esp_err_t> readSensor()` | Monadic error handling — cleaner than returning error codes |
| `std::to_underlying` | C++23 | `auto val = std::to_underlying(myEnum);` | Replaces `static_cast<int>(myEnum)` |

#### Features already available in GCC 8 (C++17)

These work on both IDF v4.4 and v5.x — prefer them now:

| Feature | Example | Notes |
|---|---|---|
| `if constexpr` | `if constexpr (sizeof(T) == 4) { ... }` | Compile-time branching; already used in WLED |
| `std::optional<T>` | `std::optional<uint8_t> pin;` | Nullable value without sentinel values like `-1` |
| `std::string_view` | `void log(std::string_view msg)` | Non-owning, non-allocating string reference |
| Structured bindings | `auto [err, value] = readSensor();` | Useful with `std::pair` / `std::tuple` returns |
| Fold expressions | `(addSegment(args), ...);` | Variadic template expansion |
| Inline variables | `inline constexpr int MAX_PINS = 50;` | Avoids ODR issues with header-defined constants |
| `[[maybe_unused]]` | `[[maybe_unused]] int debug_only = 0;` | Suppresses unused-variable warnings cleanly |
| `[[fallthrough]]` | `case 1: doA(); [[fallthrough]]; case 2:` | Documents intentional switch fallthrough |
| Nested namespaces | `namespace wled::audio { }` | Shorter than nested `namespace` blocks |

#### Patterns that break or change behavior

| Pattern | GCC 8 behavior | GCC 14 behavior | Fix |
|---|---|---|---|
| `int x; enum E e = x;` | Warning (often ignored) | Error with `-Werror=enum-conversion` | `E e = static_cast<E>(x);` |
| `int g;` in two `.cpp` files | Both compile, linker merges (tentative definition) | Error: multiple definitions (`-fno-common`) | `extern int g;` in header, `int g;` in one `.cpp` |
| `const char* ref = std::string(...).c_str();` | Silent dangling pointer | Warning (`-Wdangling-reference`) | Extend lifetime: store the `std::string` in a local variable |
| `register int x;` | Accepted (ignored) | Warning or error (`register` removed in C++17) | Remove `register` keyword |
| Narrowing in aggregate init | Warning | Error | Use explicit cast or wider type |
| Implicit `this` capture in lambdas | Accepted in `[=]` | Deprecated warning; error in C++20 mode | Use `[=, this]` or `[&]` |

<!-- HUMAN_ONLY_END -->
#### Recommendations

- **Do not raise the minimum C++ standard yet.** WLED must still build on IDF v4.4 (GCC 8.4, C++17). Use `#if __cplusplus > 201703L` to gate C++20 features.
- **Mark intentional fallthrough** with `[[fallthrough]]` — GCC 14 warns on unmarked fallthrough by default.
<!-- HUMAN_ONLY_START -->
- **Prefer `std::optional` over sentinel values** (e.g., `-1` for "no pin") in new code — it works on both compilers.
- **Use `std::string_view`** for read-only string parameters instead of `const char*` or `const String&` — zero-copy and works on GCC 8+.
- **Avoid raw `union` type punning** — prefer `memcpy` (GCC 8) or `std::bit_cast` (GCC 13+) for strict-aliasing safety.

<!-- HUMAN_ONLY_END -->
### Deprecated and removed APIs

#### RMT (Remote Control Transceiver)

The legacy `rmt_*` functions are removed in IDF v5. Do not introduce new legacy RMT calls.

<!-- HUMAN_ONLY_START -->
The new API is channel-based:

| IDF v4 (legacy) | IDF v5 (new) | Notes |
|---|---|---|
| `rmt_config()` + `rmt_driver_install()` | `rmt_new_tx_channel()` / `rmt_new_rx_channel()` | Channels are now objects |
| `rmt_write_items()` | `rmt_transmit()` with encoder | Requires `rmt_encoder_t` |
| `rmt_set_idle_level()` | Configure in channel config | Set at creation time |
| `rmt_item32_t` | `rmt_symbol_word_t` | Different struct layout |

<!-- HUMAN_ONLY_END -->
**WLED impact**: NeoPixelBus LED output and IR receiver both use legacy RMT. The upstream `V5` branch adds `-D WLED_USE_SHARED_RMT` and disables IR until the library is ported.

#### I2S (Inter-IC Sound)

Legacy `i2s_driver_install()` + `i2s_read()` API is deprecated. When touching audio source code, wrap legacy I2S init and reading in `#if ESP_IDF_VERSION_MAJOR < 5` / `#else`.

<!-- HUMAN_ONLY_START -->
 The new API uses channel handles:
| IDF v4 (legacy) | IDF v5 (new) | Notes |
|---|---|---|
| `i2s_driver_install()` | `i2s_channel_init_std_mode()` | Separate STD/PDM/TDM modes |
| `i2s_set_pin()` | Pin config in `i2s_std_gpio_config_t` | Set at init time |
| `i2s_read()` | `i2s_channel_read()` | Uses channel handle |
| `i2s_set_clk()` | `i2s_channel_reconfig_std_clk()` | Reconfigure running channel |
| `i2s_config_t` | `i2s_std_config_t` | Separate config for each mode |

**Migration pattern** (from Espressif examples):
```cpp
#if ESP_IDF_VERSION >= ESP_IDF_VERSION_VAL(5, 0, 0)
  #include "driver/i2s_std.h"
  i2s_chan_handle_t rx_handle;
  i2s_chan_config_t chan_cfg = I2S_CHANNEL_DEFAULT_CONFIG(I2S_NUM_0, I2S_ROLE_MASTER);
  i2s_new_channel(&chan_cfg, NULL, &rx_handle);

  i2s_std_config_t std_cfg = {
    .clk_cfg  = I2S_STD_CLK_DEFAULT_CONFIG(22050),
    .slot_cfg = I2S_STD_MSB_SLOT_DEFAULT_CONFIG(I2S_DATA_BIT_WIDTH_32BIT, I2S_SLOT_MODE_MONO),
    .gpio_cfg = { .din = GPIO_NUM_32, .mclk = I2S_GPIO_UNUSED, ... },
  };
  i2s_channel_init_std_mode(rx_handle, &std_cfg);
  i2s_channel_enable(rx_handle);
#else
  // Legacy i2s_driver_install() path
#endif
```
<!-- HUMAN_ONLY_END -->
**WLED impact**: The audioreactive usermod (`audio_source.h`) heavily uses legacy I2S. Migration requires rewriting the `I2SSource` class for channel-based API.

<!-- HUMAN_ONLY_START -->
#### ADC (Analog-to-Digital Converter)

Legacy `adc1_get_raw()` and `esp_adc_cal_*` are deprecated:

| IDF v4 (legacy) | IDF v5 (new) | Notes |
|---|---|---|
| `adc1_config_width()` + `adc1_get_raw()` | `adc_oneshot_new_unit()` + `adc_oneshot_read()` | Object-based API |
| `esp_adc_cal_characterize()` | `adc_cali_create_scheme_*()` | Calibration is now scheme-based |
| `adc_continuous_*` (old) | `adc_continuous_*` (restructured) | Config struct changes |

#### SPI Flash

| IDF v4 (legacy) | IDF v5 (new) |
|---|---|
| `spi_flash_read()` | `esp_flash_read()` |
| `spi_flash_write()` | `esp_flash_write()` |
| `spi_flash_erase_range()` | `esp_flash_erase_region()` |

WLED already has a compatibility shim in `ota_update.cpp` that maps old names to new ones.

#### GPIO

| IDF v4 (legacy) | IDF v5 (recommended) |
|---|---|
| `gpio_pad_select_gpio()` | `esp_rom_gpio_pad_select_gpio()` (or use `gpio_config()`) |
| `gpio_set_direction()` + `gpio_set_pull_mode()` | `gpio_config()` with `gpio_config_t` struct |

### Features disabled in IDF v5 builds

The upstream `V5` branch explicitly disables features with incompatible library dependencies:

```ini
# platformio.ini [esp32_idf_V5]
-D WLED_DISABLE_INFRARED       # IR library uses legacy RMT
-D WLED_DISABLE_MQTT            # AsyncMqttClient incompatible with IDF v5
-D ESP32_ARDUINO_NO_RGB_BUILTIN # Prevents RMT driver conflict with built-in LED
-D WLED_USE_SHARED_RMT          # Use new shared RMT driver for NeoPixel output
```

<!-- HUMAN_ONLY_END -->
### Migration checklist for new code

1. **Never use a removed API without a version guard.** Always provide both old and new paths, or disable the feature on IDF v5.
2. **Test on both IDF v4.4 and v5.x builds** if the code must be backward-compatible.
3. **Prefer the newer API** when writing new code — wrap the old API in an `#else` block.
4. **Mark migration TODOs** with `// TODO(idf5):` so they are easy to find later.

---

## Memory Management: `heap_caps_*` Best Practices

ESP32 has multiple memory regions with different capabilities. Using the right allocator is critical for performance and stability.

<!-- HUMAN_ONLY_START -->
### Memory regions

| Region | Flag | Speed | DMA | Size | Use for |
|---|---|---|---|---|---|
| DRAM | `MALLOC_CAP_INTERNAL \| MALLOC_CAP_8BIT` | Fast | Yes (ESP32) | 200–320 KB | Hot-path buffers, task stacks, small allocations |
| IRAM | `MALLOC_CAP_EXEC` | Fastest | No | 32–128 KB | Code (automatic via `IRAM_ATTR`) |
| PSRAM (SPIRAM) | `MALLOC_CAP_SPIRAM \| MALLOC_CAP_8BIT` | Slower | Chip-dependent | 2–16 MB | Large buffers, JSON documents, image data |
| RTC RAM | `MALLOC_CAP_RTCRAM` | Moderate | No | 8 KB | Data surviving deep sleep; small persistent buffers |

<!-- HUMAN_ONLY_END -->

### WLED allocation wrappers

WLED provides convenience wrappers with automatic fallback. **Always prefer these over raw `heap_caps_*` calls**:

| Function | Allocation preference | Use case |
|---|---|---|
| `d_malloc(size)` | RTC → DRAM → PSRAM | General-purpose; prefers fast memory |
| `d_calloc(n, size)` | Same as `d_malloc`, zero-initialized | Arrays, structs |
| `p_malloc(size)` | PSRAM → DRAM | Large buffers; prefers abundant memory |
| `p_calloc(n, size)` | Same as `p_malloc`, zero-initialized | Large arrays |
| `d_malloc_only(size)` | RTC → DRAM (no PSRAM fallback) | DMA buffers, time-critical data |

### PSRAM guidelines

- **Check availability**: test availability with `psramFound() && ESP.getPsramSize() > 0` before assuming PSRAM is present. Never rely on `BOARD_HAS_PSRAM`only.
- **DMA compatibility**: on ESP32 (classic), PSRAM buffers are **not DMA-capable** — use `d_malloc_only()` to allocate DMA buffers in DRAM only. On ESP32-S3 with octal PSRAM (`CONFIG_SPIRAM_MODE_OCT`), PSRAM buffers *can* be used with DMA when `CONFIG_SOC_PSRAM_DMA_CAPABLE` is defined.
- **JSON documents**: use the `PSRAMDynamicJsonDocument` allocator (defined in `wled.h`) to put large JSON documents in PSRAM:
  ```cpp
  PSRAMDynamicJsonDocument doc(16384);  // allocated in PSRAM if available
  ```
- **Fragmentation**: PSRAM allocations fragment less than DRAM because the region is larger. But avoid mixing small and large allocations in PSRAM — small allocations waste the MMU page granularity.
- **Heap validation**: use `d_measureHeap()` and `d_measureContiguousFreeHeap()` to monitor remaining DRAM. Allocations that would drop free DRAM below `MIN_HEAP_SIZE` should go to PSRAM instead.
- **Performance**: Keep hot-path data in DRAM. Prefer PSRAM for capacity-oriented buffers and monitor contiguous DRAM headroom.
<!-- HUMAN_ONLY_START -->
   PSRAM access is up to 15× slower than DRAM on ESP32, 3–10× slower than DRAM on ESP32-S3/-S2 with quad-SPI bus. On ESP32-S3 with octal PSRAM (`CONFIG_SPIRAM_MODE_OCT`), the penalty is smaller (~2×) because the 8-line DTR bus can transfer 8 bits in parallel at 80 MHz (120 MHz is possible with CONFIG_SPIRAM_SPEED_120M, which requires enabling experimental ESP-IDF features). On ESP32-P4 with hex PSRAM (`CONFIG_SPIRAM_MODE_HEX`), the 16-line bus runs at 200 MHz which brings it on-par with DRAM. Keep hot-path data in DRAM regardless, but consider that ESP32 often crashes when the largest DRAM chunk gets below 10 KB.
<!-- HUMAN_ONLY_END -->

<!-- HUMAN_ONLY_START -->
### Pattern: preference-based allocation

When you need a buffer that works on boards with or without PSRAM:

```cpp
// Prefer PSRAM for large buffers, fall back to DRAM
uint8_t* buf = (uint8_t*)heap_caps_malloc_prefer(bufSize, 2,
    MALLOC_CAP_SPIRAM | MALLOC_CAP_8BIT,   // first choice: PSRAM
    MALLOC_CAP_DEFAULT);                    // fallback: any available
// Or simply:
uint8_t* buf = (uint8_t*)p_malloc(bufSize);
```

<!-- HUMAN_ONLY_END -->
---

## I2S Audio: Best Practices

The audioreactive usermod uses I2S for microphone input. Key patterns:

### Port selection

```cpp
constexpr i2s_port_t AR_I2S_PORT = I2S_NUM_0;
// I2S_NUM_1 has limitations: no MCLK routing, no ADC support, no PDM support
```

Always use `I2S_NUM_0` unless you have a specific reason and have verified support on all target chips.

### DMA buffer tuning

DMA buffer size controls latency vs. reliability:

| Scenario | `dma_buf_count` | `dma_buf_len` | Latency | Notes |
|---|---|---|---|---|
| With HUB75 matrix | 18 | 128 | ~100 ms | Higher count prevents I2S starvation during matrix DMA |
| Without PSRAM | 24 | 128 | ~140 ms | More buffers compensate for slower interrupt response |
| Default | 8 | 128 | ~46 ms | Acceptable for most setups |

### Interrupt priority

Choose interrupt priority based on coexistence with other drivers:

```cpp
#ifdef WLED_ENABLE_HUB75MATRIX
  .intr_alloc_flags = ESP_INTR_FLAG_IRAM | ESP_INTR_FLAG_LEVEL1,  // level 1 (lowest) to avoid starving HUB75
#else
  .intr_alloc_flags = ESP_INTR_FLAG_LEVEL2 | ESP_INTR_FLAG_LEVEL3,  // accept level 2 or 3 (allocator picks available)
#endif
```

### APLL (Audio PLL) usage

The ESP32 has an audio PLL for precise sample rates. Rules:

- Enable APLL when an MCLK pin is provided and precision matters.
- **Disable APLL** when Ethernet or HUB75 is active — they also use the APLL.
- APLL is broken on ESP32 revision 0 silicon.
- Not all chips have APLL — gate with `SOC_I2S_SUPPORTS_APLL`.

```cpp
#if !defined(SOC_I2S_SUPPORTS_APLL)
  _config.use_apll = false;
#elif defined(WLED_USE_ETHERNET) || defined(WLED_ENABLE_HUB75MATRIX)
  _config.use_apll = false;  // APLL conflict
#endif
```

### PDM microphone caveats

- Not supported on ESP32-C3 (`SOC_I2S_SUPPORTS_PDM_RX` not defined).
- ESP32-S3 PDM has known issues: sample rate at 50% of expected, very low amplitude.
  - **16-bit data width**: Espressif's IDF documentation states that in PDM mode the data unit width is always 16 bits, regardless of the configured `bits_per_sample`.
  - See [espressif/esp-idf#8660](https://github.com/espressif/esp-idf/issues/8660) for the upstream issue.
  - **Flag `bits_per_sample = I2S_BITS_PER_SAMPLE_32BIT` in PDM mode** — this causes the S3 low-amplitude symptom.
- No clock pin (`I2S_CKPIN = -1`) triggers PDM mode in WLED.

---

## HUB75 LED Matrix: Best Practices

WLED uses the `ESP32-HUB75-MatrixPanel-I2S-DMA` library for HUB75 matrix output.

### Chip-specific panel limits

```cpp
#if defined(CONFIG_IDF_TARGET_ESP32S3) && defined(BOARD_HAS_PSRAM)
  maxChainLength = 6;   // S3 + PSRAM: up to 6 panels (DMA-capable PSRAM)
#elif defined(CONFIG_IDF_TARGET_ESP32S2)
  maxChainLength = 2;   // S2: limited DMA channels
#else
  maxChainLength = 4;   // Classic ESP32: default
#endif
```

### Color depth vs. pixel count

The driver dynamically reduces color depth for larger displays to stay within DMA buffer limits:

| Pixel count | Color depth | Bits per pixel |
|---|---|---|
| ≤ `MAX_PIXELS_10BIT` | 10-bit (30-bit color) | High quality (experimental) |
| ≤ `MAX_PIXELS_8BIT` | 8-bit (24-bit color) | Full quality |
| ≤ `MAX_PIXELS_6BIT` | 6-bit (18-bit color) | Slight banding |
| ≤ `MAX_PIXELS_4BIT` | 4-bit (12-bit color) | Visible banding |
| larger | 3-bit (9-bit color) | Minimal color range |

### Resource conflicts

- **APLL**: HUB75 I2S DMA uses the APLL. Disable APLL in the audio I2S driver when HUB75 is active.
- **I2S peripheral**: HUB75 uses `I2S_NUM_1` (or `I2S_NUM_0` on single-I2S chips). Audio must use the other port.
- **Pin count**: HUB75 requires 13–14 GPIO pins. On ESP32-S2 this severely limits remaining GPIO.
- **Reboot required**: on ESP32-S3, changing HUB75 driver options requires a full reboot — the I2S DMA cannot be reconfigured at runtime.

---

<!-- HUMAN_ONLY_START -->
## GPIO Best Practices

### Prefer `gpio_config()` over individual calls

```cpp
// Preferred: single struct-based configuration
gpio_config_t io_conf = {
  .pin_bit_mask = (1ULL << pin),
  .mode         = GPIO_MODE_OUTPUT,
  .pull_up_en   = GPIO_PULLUP_DISABLE,
  .pull_down_en = GPIO_PULLDOWN_DISABLE,
  .intr_type    = GPIO_INTR_DISABLE,
};
gpio_config(&io_conf);

// Avoid: multiple separate calls (more error-prone, deprecated in IDF v5)
gpio_set_direction(pin, GPIO_MODE_OUTPUT);
gpio_set_pull_mode(pin, GPIO_FLOATING);
```
<!-- HUMAN_ONLY_END -->

### Pin manager integration

Always allocate pins through WLED's `pinManager` before using GPIO APIs:

```cpp
if (!pinManager.allocatePin(myPin, true, PinOwner::UM_MyUsermod)) {
  return;  // pin in use by another module
}
// Now safe to configure
```

---

## Timer Best Practices

### Microsecond timing

For high-resolution timing, prefer `esp_timer_get_time()` (microsecond resolution, 64-bit) over `millis()` or `micros()`.
<!-- HUMAN_ONLY_START -->

```cpp
#include <esp_timer.h>
int64_t now_us = esp_timer_get_time();  // monotonic, not affected by NTP
```

> **Note**: In arduino-esp32, both `millis()` and `micros()` are thin wrappers around `esp_timer_get_time()` — they share the same monotonic clock source. Prefer the direct call when you need the full 64-bit value or ISR-safe access without truncation:
> ```cpp
> // arduino-esp32 internals (cores/esp32/esp32-hal-misc.c):
> // unsigned long micros() { return (unsigned long)(esp_timer_get_time()); }
> // unsigned long millis() { return (unsigned long)(esp_timer_get_time() / 1000ULL); }
> ```
<!-- HUMAN_ONLY_END -->
<!-- HUMAN_ONLY_START -->
### Periodic timers

For periodic tasks with sub-millisecond precision, use `esp_timer`:

```cpp
esp_timer_handle_t timer;
esp_timer_create_args_t args = {
  .callback = myCallback,
  .arg = nullptr,
  .dispatch_method = ESP_TIMER_TASK,  // run in timer task (not ISR)
  .name = "my_timer",
};
esp_timer_create(&args, &timer);
esp_timer_start_periodic(timer, 1000);  // 1 ms period
```
<!-- HUMAN_ONLY_END -->

Always prefer `ESP_TIMER_TASK` dispatch over `ESP_TIMER_ISR` unless you need ISR-level latency — ISR callbacks have severe restrictions (no logging, no heap allocation, no FreeRTOS API calls).

### Precision waiting: coarse delay then spin-poll

When waiting for a precise future deadline (e.g., FPS limiting, protocol timing), avoid spinning the entire duration — that wastes CPU and starves other tasks. Instead, yield to FreeRTOS while time allows, then spin only for the final window.
<!-- HUMAN_ONLY_START -->
```cpp
// Wait until 'target_us' (a micros() / esp_timer_get_time() timestamp)
long time_to_wait = (long)(target_us - micros());
// Coarse phase: yield to FreeRTOS while we have more than ~2 ms remaining.
// vTaskDelay(1) suspends the task for one RTOS tick, letting other task run freely.
while (time_to_wait > 2000) {
  vTaskDelay(1);
  time_to_wait = (long)(target_us - micros());
}
// Fine phase: busy-poll the last ≤2 ms for microsecond accuracy.
// micros() wraps esp_timer_get_time() so this is low-overhead.
while ((long)(target_us - micros()) > 0) { /* spin */ }
```
<!-- HUMAN_ONLY_END -->

> The threshold (2000 µs as an example) should be at least one RTOS tick (default 1 ms on ESP32) plus some margin. A value of 1500–3000 µs works well in practice.

---

## ADC Best Practices

<!-- HUMAN_ONLY_START -->
### Version-aware ADC code

ADC is one of the most fragmented APIs across IDF versions:

```cpp
#if ESP_IDF_VERSION >= ESP_IDF_VERSION_VAL(5, 0, 0)
  // IDF v5: oneshot driver
  #include "esp_adc/adc_oneshot.h"
  #include "esp_adc/adc_cali.h"
  adc_oneshot_unit_handle_t adc_handle;
  adc_oneshot_unit_init_cfg_t unit_cfg = { .unit_id = ADC_UNIT_1 };
  adc_oneshot_new_unit(&unit_cfg, &adc_handle);
#else
  // IDF v4: legacy driver
  #include "driver/adc.h"
  #include "esp_adc_cal.h"
  adc1_config_width(ADC_WIDTH_BIT_12);
  int raw = adc1_get_raw(ADC1_CHANNEL_0);
#endif
```
<!-- HUMAN_ONLY_END -->

### Bit width portability

Not all chips have 12-bit ADC. `SOC_ADC_MAX_BITWIDTH` reports the maximum resolution (12 or 13 bits). Note that in IDF v5, this macro was renamed to `CONFIG_SOC_ADC_RTC_MAX_BITWIDTH`. Write version-aware guards:

```cpp
// IDF v4: SOC_ADC_MAX_BITWIDTH   IDF v5: CONFIG_SOC_ADC_RTC_MAX_BITWIDTH
#if defined(CONFIG_SOC_ADC_RTC_MAX_BITWIDTH)   // IDF v5+
  #define MY_ADC_MAX_BITWIDTH CONFIG_SOC_ADC_RTC_MAX_BITWIDTH
#elif defined(SOC_ADC_MAX_BITWIDTH)             // IDF v4
  #define MY_ADC_MAX_BITWIDTH SOC_ADC_MAX_BITWIDTH
#else
  #define MY_ADC_MAX_BITWIDTH 12                // safe fallback
#endif

#if MY_ADC_MAX_BITWIDTH == 13
  adc1_config_width(ADC_WIDTH_BIT_13);  // ESP32-S2
#else
  adc1_config_width(ADC_WIDTH_BIT_12);  // ESP32, S3, C3, etc.
#endif
```

WLED's `util.cpp` uses the IDF v4 form (`SOC_ADC_MAX_BITWIDTH`) — this will need updating when the codebase migrates to IDF v5.

---

<!-- HUMAN_ONLY_START -->
## RMT Best Practices

### Current usage in WLED

RMT drives NeoPixel LED output (via NeoPixelBus) and IR receiver input. Both use the legacy API that is removed in IDF v5.

### Migration notes

- The upstream `V5` branch uses `-D WLED_USE_SHARED_RMT` to switch to the new RMT driver for NeoPixel output.
- IR is disabled on IDF v5 until the IR library is ported.
- New chips (C6, P4) have different RMT channel counts — use `SOC_RMT_TX_CANDIDATES_PER_GROUP` to check availability.
- The new RMT API requires an "encoder" object (`rmt_encoder_t`) to translate data formats — this is more flexible but requires more setup code.

<!-- HUMAN_ONLY_END -->
---

## Espressif Best Practices (from official examples)

### Error handling

Always check `esp_err_t` return values. Use `ESP_ERROR_CHECK()` in initialization code, but handle errors gracefully in runtime code.
<!-- HUMAN_ONLY_START -->
```cpp
// Initialization — crash early on failure
ESP_ERROR_CHECK(i2s_driver_install(I2S_NUM_0, &config, 0, nullptr));

// Runtime — log and recover
esp_err_t err = i2s_read(I2S_NUM_0, buf, len, &bytes_read, portMAX_DELAY);
if (err != ESP_OK) {
  DEBUGSR_PRINTF("I2S read failed: %s\n", esp_err_to_name(err));
  return;
}
```
<!-- HUMAN_ONLY_END -->

For situations between these two extremes — where you want the `ESP_ERROR_CHECK` formatted log message (file, line, error name) but must not abort — use `ESP_ERROR_CHECK_WITHOUT_ABORT()`.

<!-- HUMAN_ONLY_START -->
```cpp
// Logs in the same format as ESP_ERROR_CHECK, but returns the error code instead of aborting.
// Useful for non-fatal driver calls where you want visibility without crashing.
esp_err_t err = ESP_ERROR_CHECK_WITHOUT_ABORT(i2s_set_clk(AR_I2S_PORT, rate, bits, ch));
if (err != ESP_OK) return;  // handle as needed
```

<!-- HUMAN_ONLY_END -->
### Logging

WLED uses its own logging macros — **not** `ESP_LOGx()`. For application-level code, always use the WLED macros defined in `wled.h`:

| Macro family | Defined in | Controlled by | Use for |
|---|---|---|---|
| `DEBUG_PRINT` / `DEBUG_PRINTLN` / `DEBUG_PRINTF` | `wled.h` | `WLED_DEBUG` build flag | Development/diagnostic output; compiled out in release builds |

All of these wrap `Serial` output through the `DEBUGOUT` / `DEBUGOUTLN` / `DEBUGOUTF` macros.

**Exception — low-level driver code**: When writing code that interacts directly with ESP-IDF APIs (e.g., I2S initialization, RMT setup), use `ESP_LOGx()` macros instead. They support tag-based filtering and compile-time log level control:

<!-- HUMAN_ONLY_START -->
```cpp
static const char* TAG = "my_module";
ESP_LOGI(TAG, "Initialized with %d buffers", count);
ESP_LOGW(TAG, "PSRAM not available, falling back to DRAM");
ESP_LOGE(TAG, "Failed to allocate %u bytes", size);
```
<!-- HUMAN_ONLY_END -->
### Task creation and pinning

<!-- HUMAN_ONLY_START -->
On dual-core chips (ESP32, S3, P4), pin latency-sensitive tasks to a specific core:

```cpp
xTaskCreatePinnedToCore(
  audioTask,        // function
  "audio",          // name
  4096,             // stack size
  nullptr,          // parameter
  5,                // priority (higher = more important)
  &audioTaskHandle, // handle
  0                 // core ID (0 = protocol core, 1 = app core)
);
```
<!-- HUMAN_ONLY_END -->

Guidelines:
- Pin network/protocol tasks to core 0 (where Wi-Fi runs).
- Pin real-time tasks (audio, LED output) to core 1.
- On single-core chips (S2, C3, C5, C6), only core 0 exists — pinning to core 1 will fail. Use `SOC_CPU_CORES_NUM > 1` guards or `tskNO_AFFINITY`.
- Use `SOC_CPU_CORES_NUM` to conditionally pin tasks:
  ```cpp
  #if SOC_CPU_CORES_NUM > 1
    xTaskCreatePinnedToCore(audioTask, "audio", 4096, nullptr, 5, &handle, 1);
  #else
    xTaskCreate(audioTask, "audio", 4096, nullptr, 5, &handle);
  #endif
  ```

**Tip: use xTaskCreateUniversal()** - from arduino-esp32 - to avoid the conditional on `SOC_CPU_CORES_NUM`. This function has the same signature as ``xTaskCreatePinnedToCore()``, but automatically falls back to ``xTaskCreate()`` on single-core MCUs.

### `delay()`, `yield()`, and the IDLE task

FreeRTOS on ESP32 is **preemptive** — all tasks are scheduled by priority regardless of `yield()` calls. This is fundamentally different from ESP8266 cooperative multitasking.

<!-- HUMAN_ONLY_START -->
| Call | What it does | Reaches IDLE (priority 0)? |
|---|---|---|
| `delay(ms)` / `vTaskDelay(ticks)` | Suspends calling task; scheduler runs all other ready tasks | ✅ Yes |
| `yield()` / `vTaskDelay(0)` | Hint to switch to tasks at **equal or higher** priority only | ❌ No |
| `taskYIELD()` | Same as `vTaskDelay(0)` | ❌ No |
| Blocking API (`xQueueReceive`, `ulTaskNotifyTake`, `vTaskDelayUntil`) | Suspends task until event or timeout; IDLE runs freely | ✅ Yes |

<!-- HUMAN_ONLY_END -->

**`delay()` in `loopTask` is safe.** Arduino's `loop()` runs inside `loopTask`. Calling `delay()` suspends only `loopTask` — all other FreeRTOS tasks (Wi-Fi stack, audio FFT, LED DMA) continue uninterrupted on either core.

**`yield()` does not yield to IDLE.** Any task that loops with only `yield()` calls will starve the IDLE task, causing the IDLE watchdog to fire. Always use `delay(1)` (or a blocking FreeRTOS call) in tight task loops. Note: WLED redefines `yield()` as an empty macro on ESP32 WLEDMM_FASTPATH builds.

#### Why the IDLE task is not optional
<!-- HUMAN_ONLY_START -->

The FreeRTOS IDLE task (one per core on dual-core ESP32 and ESP32-S3; single instance on single-core chips) is not idle in the casual sense — it performs essential system housekeeping:

- **Frees deleted task memory**: when a task calls `vTaskDelete()`, the IDLE task reclaims its TCB and stack. Without IDLE running, deleted tasks leak memory permanently.
- **Runs the idle hook**: when `configUSE_IDLE_HOOK = 1`, the IDLE task calls `vApplicationIdleHook()` on every iteration — some ESP-IDF components register low-priority background work here.
- **Implements tickless idle / light sleep**: on battery-powered devices, IDLE is the entry point for low-power sleep. A permanently starved IDLE task disables light sleep entirely.
- **Runs registered idle hooks**: ESP-IDF components register callbacks via `esp_register_freertos_idle_hook()` (e.g., Wi-Fi background maintenance, Bluetooth housekeeping). These only fire when IDLE runs.

<!-- HUMAN_ONLY_END -->

In short: **starving IDLE corrupts memory cleanup, breaks background activities, disables low-power sleep, and prevents Wi-Fi/BT maintenance.** The IDLE watchdog panic is a symptom — the real damage happens before the watchdog fires.

### Watchdog management

Long-running operations may trigger the task watchdog. Feed it explicitly:

```cpp
#include <esp_task_wdt.h>
esp_task_wdt_reset();  // feed the watchdog in long loops
```

For tasks that intentionally block for extended periods, consider subscribing/unsubscribing from the TWDT:

```cpp
esp_task_wdt_delete(NULL);  // remove current task from TWDT (IDF v4.4)
// ... long blocking operation ...
esp_task_wdt_add(NULL);     // re-register
```

> **IDF v5 note**: In IDF v5, `esp_task_wdt_add()` and `esp_task_wdt_delete()` require an explicit `TaskHandle_t`. Use `xTaskGetCurrentTaskHandle()` instead of `NULL`.

<!-- HUMAN_ONLY_START -->
---

## Quick Reference: IDF v4 → v5 API Mapping

| Component | IDF v4 Header | IDF v5 Header | Key Change |
|---|---|---|---|
| I2S | `driver/i2s.h` | `driver/i2s_std.h` | Channel-based API |
| ADC (oneshot) | `driver/adc.h` | `esp_adc/adc_oneshot.h` | Unit/channel handles |
| ADC (calibration) | `esp_adc_cal.h` | `esp_adc/adc_cali.h` | Scheme-based calibration |
| RMT | `driver/rmt.h` | `driver/rmt_tx.h` / `rmt_rx.h` | Encoder-based transmit |
| SPI Flash | `spi_flash.h` | `esp_flash.h` | `esp_flash_*` functions |
| GPIO | `driver/gpio.h` | `driver/gpio.h` | `gpio_pad_select_gpio()` removed |
| Timer | `driver/timer.h` | `driver/gptimer.h` | General-purpose timer handles |
| PCNT | `driver/pcnt.h` | `driver/pulse_cnt.h` | Handle-based API |
<!-- HUMAN_ONLY_END -->

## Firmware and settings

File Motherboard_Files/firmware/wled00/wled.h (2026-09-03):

#ifndef WLED_H
#define WLED_H
/*
   Main sketch, global variable declarations
   @title WLED project sketch
   @author Christian Schwinne
 */

// version code in format yymmddb (b = daily build)
#define VERSION 2605010

//uncomment this if you have a "my_config.h" file you'd like to use
//#define WLED_USE_MY_CONFIG

// ESP8266-01 (blue) got too little storage space to work with WLED. 0.10.2 is the last release supporting this unit.

// ESP8266-01 (black) has 1MB flash and can thus fit the whole program, although OTA update is not possible. Use 1M(128K SPIFFS).
// 2-step OTA may still be possible: https://github.com/wled-dev/WLED/issues/2040#issuecomment-981111096
// Uncomment some of the following lines to disable features:
// Alternatively, with platformio pass your chosen flags to your custom build target in platformio_override.ini

// You are required to disable over-the-air updates:
//#define WLED_DISABLE_OTA         // saves 14kb
#ifdef WLED_ENABLE_AOTA
  #if defined(WLED_DISABLE_OTA)
    #warning WLED_DISABLE_OTA was defined but it will be ignored due to WLED_ENABLE_AOTA.
  #endif
  #undef WLED_DISABLE_OTA
#endif

// You can choose some of these features to disable:
//#define WLED_DISABLE_ALEXA       // saves 11kb
//#define WLED_DISABLE_HUESYNC     // saves 4kb
//#define WLED_DISABLE_INFRARED    // saves 12kb, there is no pin left for this on ESP8266-01
#ifndef WLED_DISABLE_MQTT
  #define WLED_ENABLE_MQTT         // saves 12kb
#endif
#ifndef WLED_DISABLE_ADALIGHT      // can be used to disable reading commands from serial RX pin (see issue #3128).
  #define WLED_ENABLE_ADALIGHT     // disable saves 5Kb (uses GPIO3 (RX) for serial). Related serial protocols: Adalight/TPM2, Improv, Serial JSON, Continuous Serial Streaming
#else
  #undef WLED_ENABLE_ADALIGHT      // disable has priority over enable
#endif
//#define WLED_ENABLE_DMX          // uses 3.5kb
#ifndef WLED_DISABLE_LOXONE
  #define WLED_ENABLE_LOXONE       // uses 1.2kb
#endif
#ifndef WLED_DISABLE_WEBSOCKETS
  #define WLED_ENABLE_WEBSOCKETS
#else
  #define WLED_ENABLE_JSONLIVE     // peek LED output via /json/live (WS binary peek is always enabled)
#endif

//#define WLED_DISABLE_ESPNOW      // Removes dependence on esp now

#define WLED_ENABLE_FS_EDITOR      // enable /edit page for editing FS content. Will also be disabled with OTA lock

// to toggle usb serial debug (un)comment the following line
//#define WLED_DEBUG

// filesystem specific debugging
//#define WLED_DEBUG_FS

#ifndef WLED_WATCHDOG_TIMEOUT
  // 3 seconds should be enough to detect a lockup
  // define WLED_WATCHDOG_TIMEOUT=0 to disable watchdog, default
  #define WLED_WATCHDOG_TIMEOUT 0
#endif

//optionally disable brownout detector on ESP32.
//This is generally a terrible idea, but improves boot success on boards with a 3.3v regulator + cap setup that can't provide 400mA peaks
//#define WLED_DISABLE_BROWNOUT_DET

#include <cstddef>
#include <vector>

// Library inclusions.
#include <Arduino.h>
#ifdef ESP8266
  #include <ESP8266WiFi.h>
  #ifdef WLED_ENABLE_WPA_ENTERPRISE
    #include "wpa2_enterprise.h"
  #endif
  #include <ESP8266mDNS.h>
  #include <ESPAsyncTCP.h>
  #include <LittleFS.h>
  extern "C"
  {
  #include <user_interface.h>
  }
  #ifndef WLED_DISABLE_ESPNOW
    #include <espnow.h>
    #define WIFI_MODE_STA WIFI_STA
    #define WIFI_MODE_AP WIFI_AP
    #include <QuickEspNow.h>
  #endif
#else // ESP32
  #include <HardwareSerial.h>  // ensure we have the correct "Serial" on new MCUs (depends on ARDUINO_USB_MODE and ARDUINO_USB_CDC_ON_BOOT)
  #include <WiFi.h>
  #include <ETH.h>
  #include "esp_wifi.h"
  #include <ESPmDNS.h>
  #include <AsyncTCP.h>
  #if LOROL_LITTLEFS
    #ifndef CONFIG_LITTLEFS_FOR_IDF_3_2
      #define CONFIG_LITTLEFS_FOR_IDF_3_2
    #endif
    #include <LITTLEFS.h>
  #else
    #include <LittleFS.h>
  #endif
  #include "esp_task_wdt.h"

  #ifndef WLED_DISABLE_ESPNOW
    #include <esp_now.h>
    #include <QuickEspNow.h>
  #endif
#endif
#include <Wire.h>
#include <SPI.h>

#include "src/dependencies/network/Network.h"

#ifdef WLED_USE_MY_CONFIG
  #include "my_config.h"
#endif

#include <ESPAsyncWebServer.h>
#include <WiFiUdp.h>
#include <DNSServer.h>
#include <SPIFFSEditor.h>
#include "src/dependencies/time/TimeLib.h"
#include "src/dependencies/timezone/Timezone.h"
#include "src/dependencies/toki/Toki.h"

#ifndef WLED_DISABLE_ALEXA
  #define ESPALEXA_ASYNC
  #define ESPALEXA_NO_SUBPAGE
  #define ESPALEXA_MAXDEVICES 10
  // #define ESPALEXA_DEBUG
  #include "src/dependencies/espalexa/Espalexa.h"
  #include "src/dependencies/espalexa/EspalexaDevice.h"
#endif

#ifdef WLED_ENABLE_DMX
 #if defined(ESP8266) || defined(CONFIG_IDF_TARGET_ESP32C3) || defined(CONFIG_IDF_TARGET_ESP32S2)
  #include "src/dependencies/dmx/ESPDMX.h"
 #else //ESP32
  #include "src/dependencies/dmx/SparkFunDMX.h"
 #endif
#endif

#ifdef WLED_ENABLE_DMX_INPUT
  #include "dmx_input.h"
#endif

#include "src/dependencies/e131/ESPAsyncE131.h"
#ifndef WLED_DISABLE_MQTT
#include <AsyncMqttClient.h>
#endif

#define ARDUINOJSON_DECODE_UNICODE 0
#include "src/dependencies/json/AsyncJson-v6.h"
#include "src/dependencies/json/ArduinoJson-v6.h"

// ESP32-WROVER features SPI RAM (aka PSRAM) which can be allocated using ps_malloc()
// we can create custom PSRAMDynamicJsonDocument to use such feature (replacing DynamicJsonDocument)
// The following is a construct to enable code to compile without it.
// There is a code that will still not use PSRAM though:
//    AsyncJsonResponse is a derived class that implements DynamicJsonDocument (AsyncJson-v6.h)
#if defined(BOARD_HAS_PSRAM)
struct PSRAM_Allocator {
  void* allocate(size_t size) {
    return ps_malloc(size); // use PSRAM
  }
  void* reallocate(void* ptr, size_t new_size) {
    return ps_realloc(ptr, new_size); // use PSRAM
  }
  void deallocate(void* pointer) {
    free(pointer);
  }
};
using PSRAMDynamicJsonDocument = BasicJsonDocument<PSRAM_Allocator>;
#else
#define PSRAMDynamicJsonDocument DynamicJsonDocument
#endif

#define FASTLED_INTERNAL //remove annoying pragma messages
#define USE_GET_MILLISECOND_TIMER

#include "const.h"
#include "colors.h"
#include "fcn_declare.h"
#ifndef WLED_DISABLE_OTA
  #include "ota_update.h"
#endif
#include "NodeStruct.h"
#include "pin_manager.h"
#include "bus_manager.h"
#include "FX.h"
#include "wled_metadata.h"

#ifndef CLIENT_SSID
  #define CLIENT_SSID DEFAULT_CLIENT_SSID
#endif

#ifndef CLIENT_PASS
  #define CLIENT_PASS ""
#endif

#ifndef MDNS_NAME
  #define MDNS_NAME DEFAULT_MDNS_NAME
#endif

#if defined(WLED_AP_PASS) && !defined(WLED_AP_SSID)
  #error WLED_AP_PASS is defined but WLED_AP_SSID is still the default. \
         Please change WLED_AP_SSID to something unique.
#endif

#ifndef WLED_AP_SSID
  #define WLED_AP_SSID DEFAULT_AP_SSID
#endif

#ifndef WLED_AP_PASS
  #define WLED_AP_PASS DEFAULT_AP_PASS
#endif

#ifndef WLED_PIN
  #define WLED_PIN ""
#endif
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
